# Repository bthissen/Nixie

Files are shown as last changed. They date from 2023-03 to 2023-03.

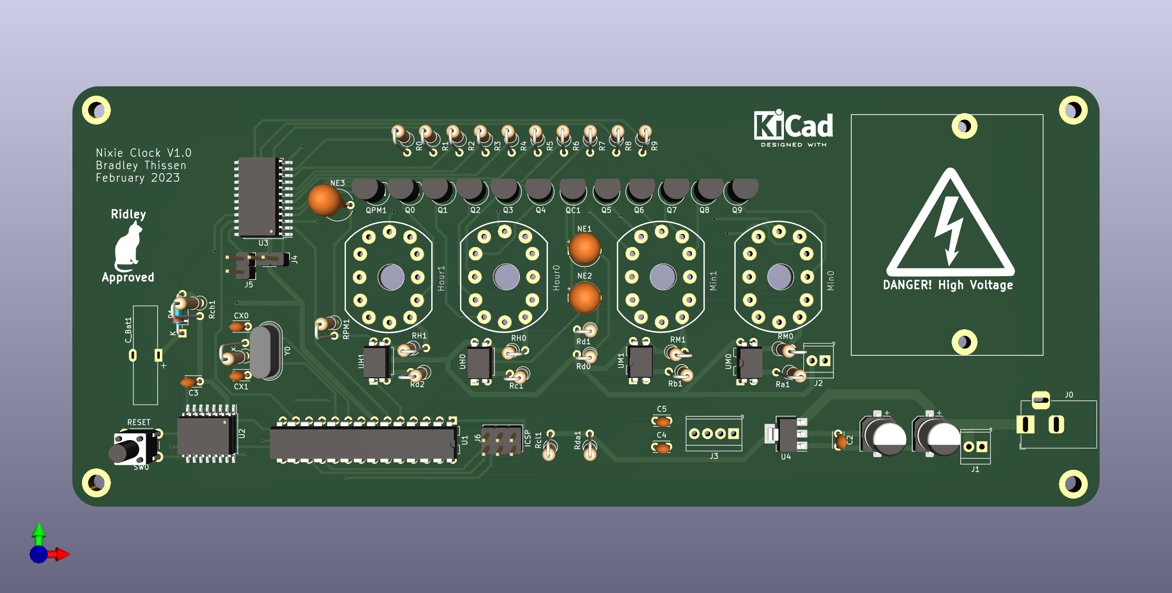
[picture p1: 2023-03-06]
Photos/v1/nixie_clock.png

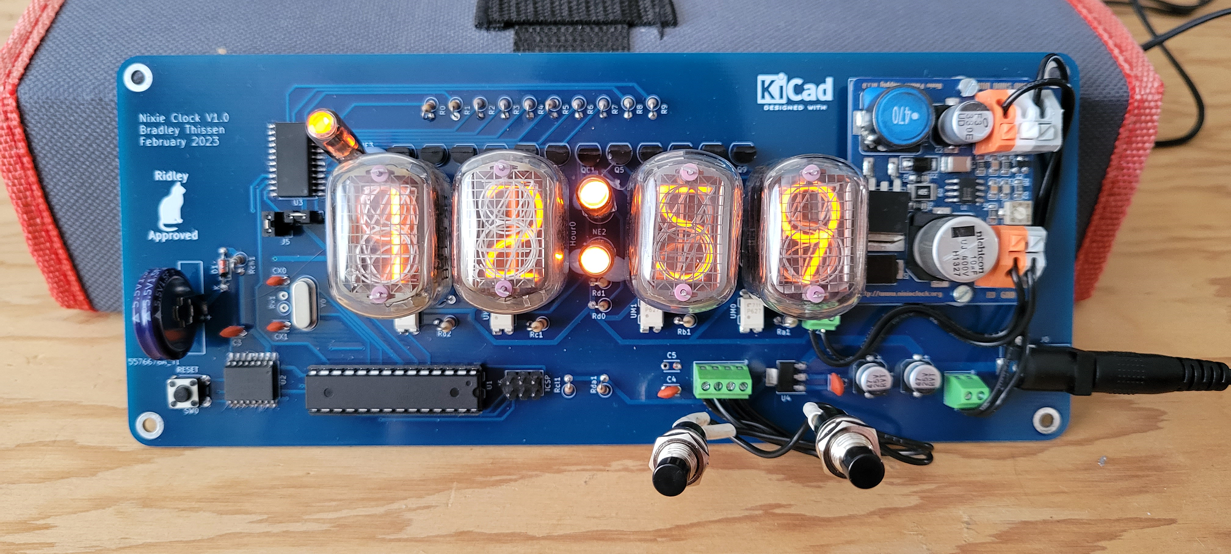
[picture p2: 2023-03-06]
Photos/v1/working_clock.png

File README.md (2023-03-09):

# Nixie

This is the control program for a Nixie Clock using an ATMEGA 328p uC coupled with a DS3231M RTC to maintain and read-back the time
to IN-12B Nixie Tubes and signal with INS-1 Neon indicators (for AM/PM and colon blink). Code is in C and pre-compiled with necessary
.hex to flash directly if needed (need USBASP programmer with ICSP protocol).

Also incluced are KiCAD schematic and PCB files for editing if desired and compiled gerber files for PCB manufacured if wanted. (note: circuit
uses a CD74HC4514 4-to-16 mux to drive the nixie tubes.

#v1.0 initial publish of working model and PCB (currently not using twi.c or twi.h; plan to incorporate for ease of use for TWI protocol
#v1.5 incorporated twi.c and twi.h files for (I2C) implementation (and future modularity); also added 12hr/24hr toggle mode for UI

USAGE:
clock display using 4 nixie tubes arranged as hour(10's) | hour(1's) | minute(10's) | minute(1's) with blinking ':' indicator and 'PM' neon light represent
time over 12 hours (12hr mode only).

Time Setting:
two buttons (set and increment) are used to allow for user program of time and mode. If set button not pressed, increment button acts as toggle mode 
which will switch display from 12 hour to 24 hour and vice-versa.

to set time, press set button once (colon indicator will freeze) and select minutes with increment button to cycle minutes from 0 to 59. Once minutes is decided 
press set button again to increment hours using same increment button (1 to 12 in 12 hr mode; 0 to 24 in 24hr mode). Once hours is selected press set button for 
final time to program time. If done correctly displayed time will be written to DS3231 RTC and colon indicator will begin to blink again.

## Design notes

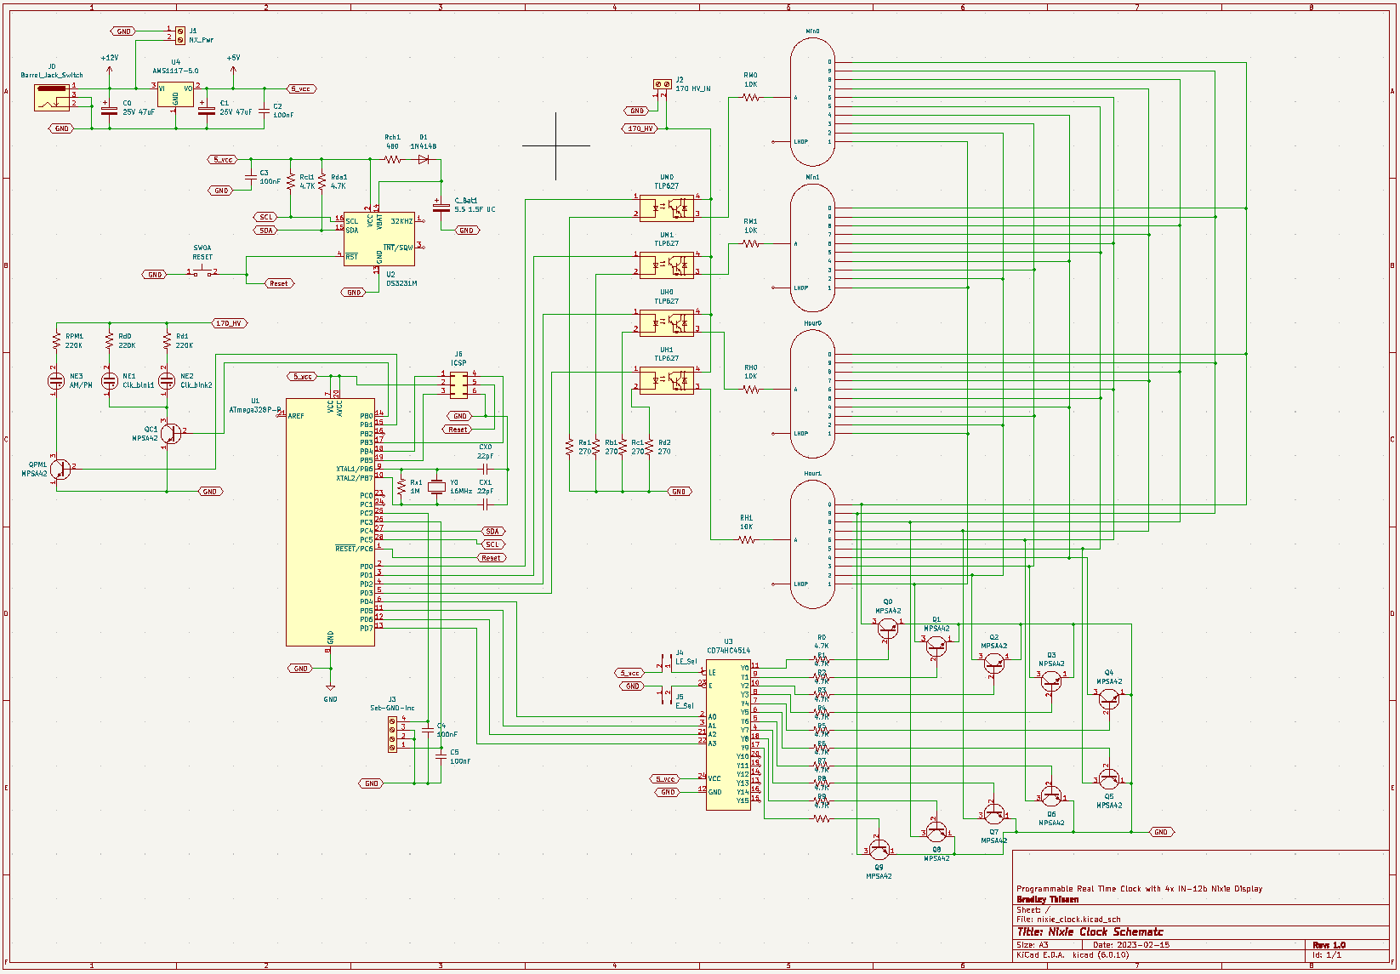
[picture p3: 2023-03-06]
Photos/v1/schematic.PNG

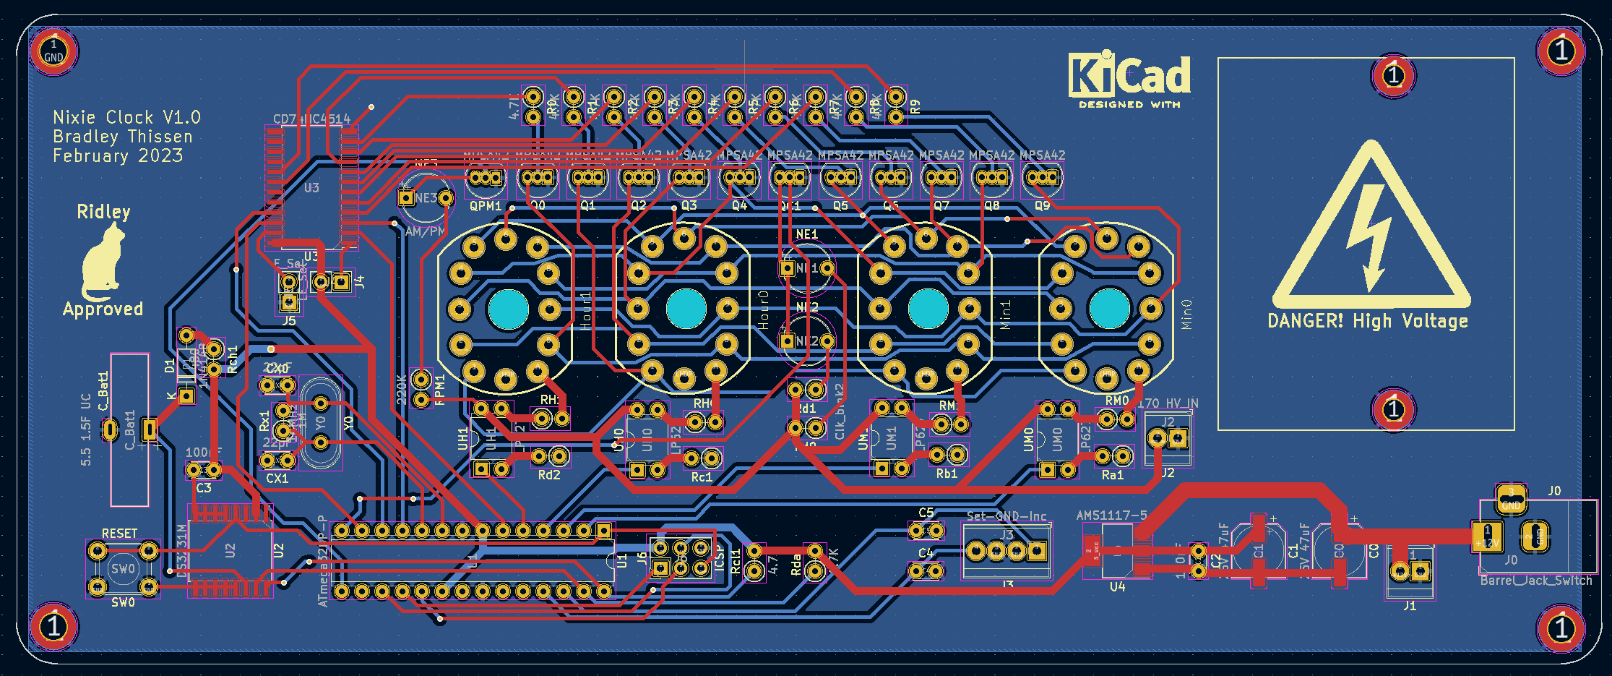
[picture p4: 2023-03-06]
Photos/v1/pcb.PNG

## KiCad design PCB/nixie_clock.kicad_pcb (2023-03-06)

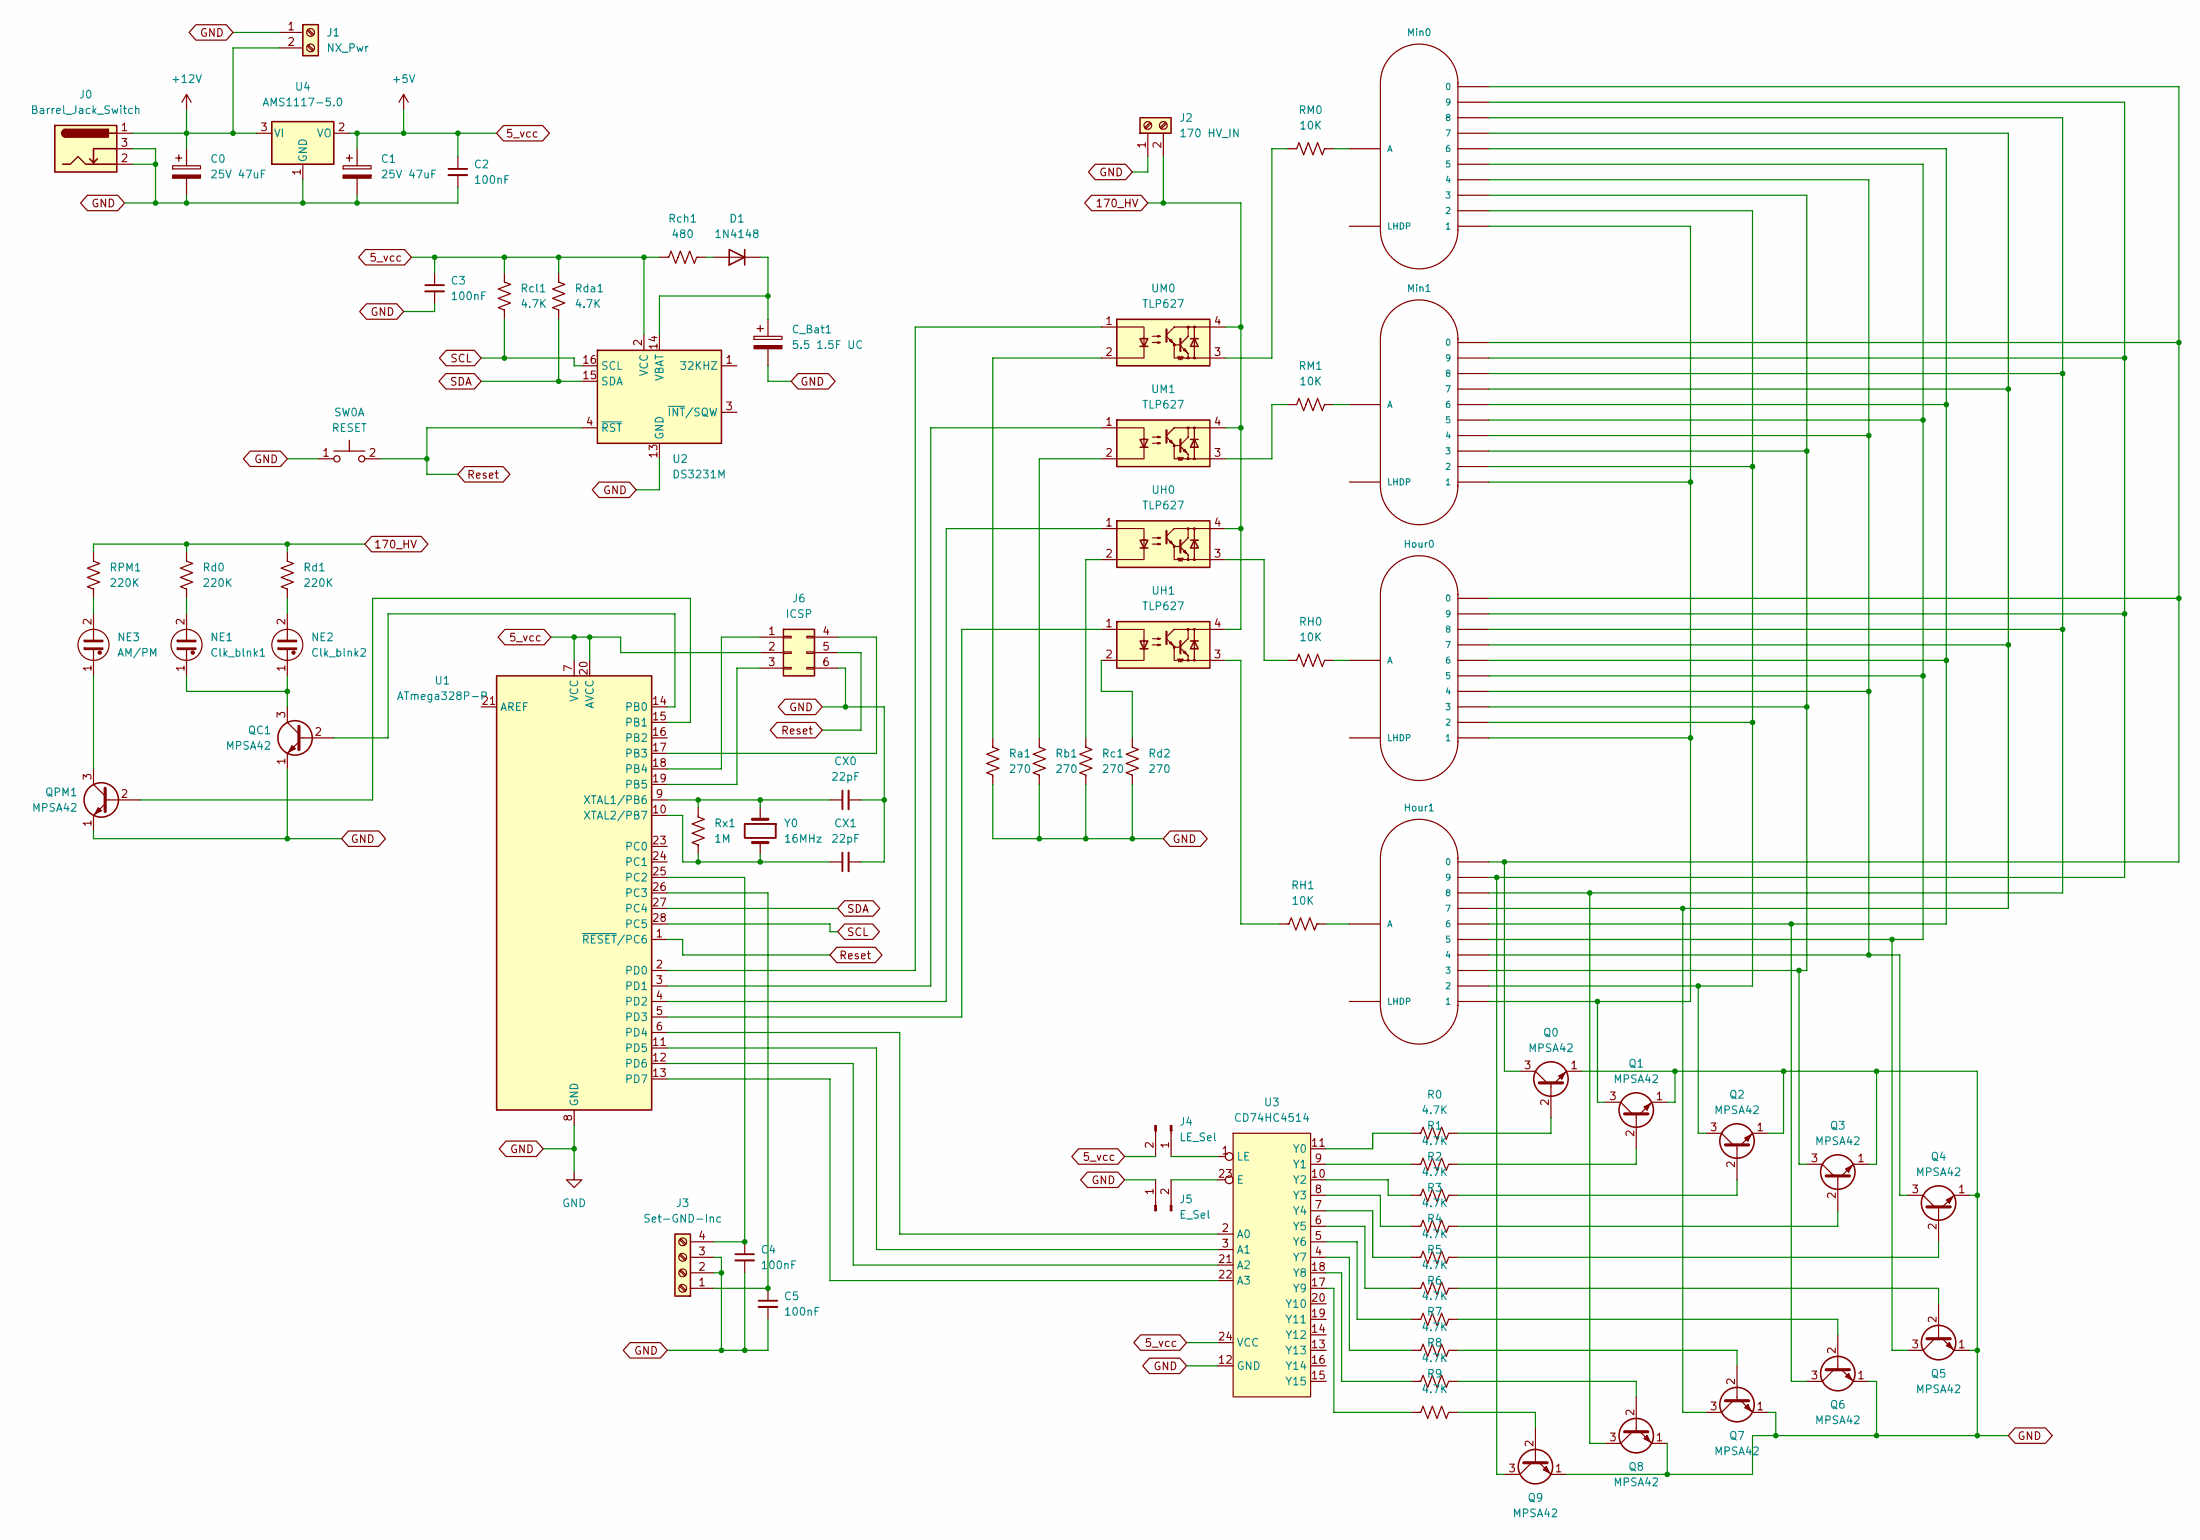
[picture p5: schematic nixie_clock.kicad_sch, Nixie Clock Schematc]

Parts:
C0, C1: 25V 47uF; CP_Elec_6.3x5.9
C2, C3, C4, C5: 100nF; C_Disc_D3.0mm_W2.0mm_P2.50mm
CX0, CX1: 22pF; C_Disc_D3.0mm_W2.0mm_P2.50mm
C_Bat1: 5.5 1.5F UC; DX_5R5VxxxxU_D19.0mm_P5.00mm
D1: 1N4148; D_DO-35_SOD27_P7.62mm_Horizontal
Hour0, Hour1: IN-12BORIGINAL; IN-12
J0: Barrel_Jack_Switch; BarrelJack_Horizontal
J1: NX_Pwr; TerminalBlock_TE_282834-2_1x02_P2.54mm_Horizontal
J2: 170 HV_IN; TerminalBlock_TE_282834-2_1x02_P2.54mm_Horizontal
J3: Set-GND-Inc; TerminalBlock_TE_282834-4_1x04_P2.54mm_Horizontal
J4: LE_Sel; PinHeader_1x02_P2.54mm_Vertical
J5: E_Sel; PinHeader_1x02_P2.54mm_Vertical
J6: ICSP; PinHeader_2x03_P2.54mm_Vertical
Min0, Min1: IN-12BORIGINAL; IN-12
NE1: Clk_blnk1; CP_Radial_Tantal_D6.0mm_P5.00mm
NE2: Clk_blnk2; CP_Radial_Tantal_D6.0mm_P5.00mm
NE3: AM/PM; CP_Radial_Tantal_D6.0mm_P5.00mm
Q0, Q1, Q2, Q3, Q4, Q5, Q6, Q7, Q8, Q9: MPSA42; TO-92_Inline
QC1: MPSA42; TO-92_Inline
QPM1: MPSA42; TO-92_Inline
R0, R1, R2, R3, R4, R5, R6, R7, R8, R9: 4.7K; R_Axial_DIN0207_L6.3mm_D2.5mm_P2.54mm_Vertical
RH0, RH1: 10K; R_Axial_DIN0207_L6.3mm_D2.5mm_P2.54mm_Vertical
RM0, RM1: 10K; R_Axial_DIN0207_L6.3mm_D2.5mm_P2.54mm_Vertical
RPM1: 220K; R_Axial_DIN0207_L6.3mm_D2.5mm_P2.54mm_Vertical
Ra1: 270; R_Axial_DIN0207_L6.3mm_D2.5mm_P2.54mm_Vertical
Rb1: 270; R_Axial_DIN0207_L6.3mm_D2.5mm_P2.54mm_Vertical
Rc1: 270; R_Axial_DIN0207_L6.3mm_D2.5mm_P2.54mm_Vertical
Rch1: 480; R_Axial_DIN0207_L6.3mm_D2.5mm_P2.54mm_Vertical
Rcl1: 4.7K; R_Axial_DIN0207_L6.3mm_D2.5mm_P2.54mm_Vertical
Rd0, Rd1: 220K; R_Axial_DIN0207_L6.3mm_D2.5mm_P2.54mm_Vertical
Rd2: 270; R_Axial_DIN0207_L6.3mm_D2.5mm_P2.54mm_Vertical
Rda1: 4.7K; R_Axial_DIN0207_L6.3mm_D2.5mm_P2.54mm_Vertical
Rx1: 1M; R_Axial_DIN0207_L6.3mm_D2.5mm_P2.54mm_Vertical
SW0: RESET; SW_PUSH_6mm_H7.3mm
U1: ATmega328P-P; DIP-28_W7.62mm
U2: DS3231M; SOIC-16W_7.5x10.3mm_P1.27mm
U3: CD74HC4514; SOIC-24
U4: AMS1117-5.0; SOT-223-3_TabPin2
UH0, UH1: TLP627; DIP-4_W7.62mm
UM0, UM1: TLP627; DIP-4_W7.62mm
Y0: 16MHz; Crystal_HC49-4H_Vertical

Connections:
5_vcc: C1.1, C2.1, C3.1, J4.2, J6.2, Rch1.2, Rcl1.2, Rda1.2, U1.7 (VCC), U1.20 (AVCC), U2.2 (VCC), U3.24 (VCC), U4.2 (VO)
170_HV: J2.2, RPM1.2, Rd0.2, Rd1.2, UH0.4, UH1.4, UM0.4, UM1.4
+12V: C0.1, J0.1, J1.2, U4.3 (VI)
GND: C0.2, C1.2, C2.2, C3.2, C4.2, C5.2, CX0.2, CX1.2, C_Bat1.2, J0.2, J0.3, J1.1, J2.1, J3.2, J3.3, J5.1, J6.6, Q0.1 (E), Q1.1 (E), Q2.1 (E), Q3.1 (E), Q4.1 (E), Q5.1 (E), Q6.1 (E), Q7.1 (E), Q8.1 (E), Q9.1 (E), QC1.1 (E), QPM1.1 (E), Ra1.1, Rb1.1, Rc1.1, Rd2.1, SW0.1 (C), U1.8 (GND), U1.22 (GND), U2.5 (GND), U2.6 (GND), U2.7 (GND), U2.8 (GND), U2.9 (GND), U2.10 (GND), U2.11 (GND), U2.12 (GND), U2.13 (GND), U3.12 (GND), U4.1 (GND)
unnamed: C_Bat1.1, D1.1 (K), U2.14 (VBAT)
unnamed: D1.2 (A), Rch1.1
unnamed: Hour0.A, RH0.2
unnamed: Hour0.0, Hour1.0, Min0.0, Min1.0, Q0.3 (C)
unnamed: Hour0.1, Hour1.1, Min0.1, Min1.1, Q1.3 (C)
unnamed: Hour0.2, Hour1.2, Min0.2, Min1.2, Q2.3 (C)
unnamed: Hour0.3, Hour1.3, Min0.3, Min1.3, Q3.3 (C)
unnamed: Hour0.4, Hour1.4, Min0.4, Min1.4, Q4.3 (C)
unnamed: Hour0.5, Hour1.5, Min0.5, Min1.5, Q5.3 (C)
unnamed: Hour0.6, Hour1.6, Min0.6, Min1.6, Q6.3 (C)
unnamed: Hour0.7, Hour1.7, Min0.7, Min1.7, Q7.3 (C)
unnamed: Hour0.8, Hour1.8, Min0.8, Min1.8, Q8.3 (C)
unnamed: Hour0.9, Hour1.9, Min0.9, Min1.9, Q9.3 (C)
unnamed: Hour1.A, RH1.2
unnamed: C5.1, J3.1, U1.26 (PC3)
unnamed: J4.1, U3.1 (LE)
unnamed: J5.2, U3.23 (E)
unnamed: J6.1, U1.18 (PB4)
unnamed: J6.3, U1.19 (PB5)
unnamed: J6.4, U1.17 (PB3)
unnamed: Min0.A, RM0.2
unnamed: Min1.A, RM1.2
unnamed: NE1.1, NE2.1, QC1.3 (C)
unnamed: NE1.2, Rd0.1
unnamed: NE2.2, Rd1.1
unnamed: NE3.1, QPM1.3 (C)
unnamed: NE3.2, RPM1.1
unnamed: Q0.2 (B), R0.2
unnamed: Q1.2 (B), R1.2
unnamed: Q2.2 (B), R2.2
unnamed: Q3.2 (B), R3.2
unnamed: Q4.2 (B), R4.2
unnamed: Q5.2 (B), R5.2
unnamed: Q6.2 (B), R6.2
unnamed: Q7.2 (B), R7.2
unnamed: Q8.2 (B), R8.2
unnamed: Q9.2 (B), R9.2
unnamed: QC1.2 (B), U1.14 (PB0)
unnamed: QPM1.2 (B), U1.15 (PB1)
unnamed: RH0.1, UH0.3
unnamed: RH1.1, UH1.3
unnamed: RM0.1, UM0.3
unnamed: RM1.1, UM1.3
unnamed: Ra1.2, UM0.2
unnamed: Rb1.2, UM1.2
unnamed: Rc1.2, UH0.2
unnamed: Rd2.2, UH1.2
unnamed: U1.2 (PD0), UM0.1
unnamed: U1.3 (PD1), UM1.1
unnamed: U1.4 (PD2), UH0.1
unnamed: U1.5 (PD3), UH1.1
unnamed: U1.6 (PD4), U3.2 (A0)
unnamed: CX0.1, Rx1.2, U1.9 (XTAL1/PB6), Y0.1
unnamed: CX1.1, Rx1.1, U1.10 (XTAL2/PB7), Y0.2
unnamed: U1.11 (PD5), U3.3 (A1)
unnamed: U1.12 (PD6), U3.21 (A2)
unnamed: U1.13 (PD7), U3.22 (A3)
unnamed: C4.1, J3.4, U1.25 (PC2)
unnamed: R7.1, U3.4 (Y7)
unnamed: R6.1, U3.5 (Y6)
unnamed: R5.1, U3.6 (Y5)
unnamed: R4.1, U3.7 (Y4)
unnamed: R3.1, U3.8 (Y3)
unnamed: R1.1, U3.9 (Y1)
unnamed: R2.1, U3.10 (Y2)
unnamed: R0.1, U3.11 (Y0)
unnamed: R9.1, U3.17 (Y9)
unnamed: R8.1, U3.18 (Y8)
Reset: J6.5, SW0.2 (D), U1.1 (~RESET/PC6), U2.4 (~RST)
SCL: Rcl1.1, U1.28 (PC5), U2.16 (SCL)
SDA: Rda1.1, U1.27 (PC4), U2.15 (SDA)

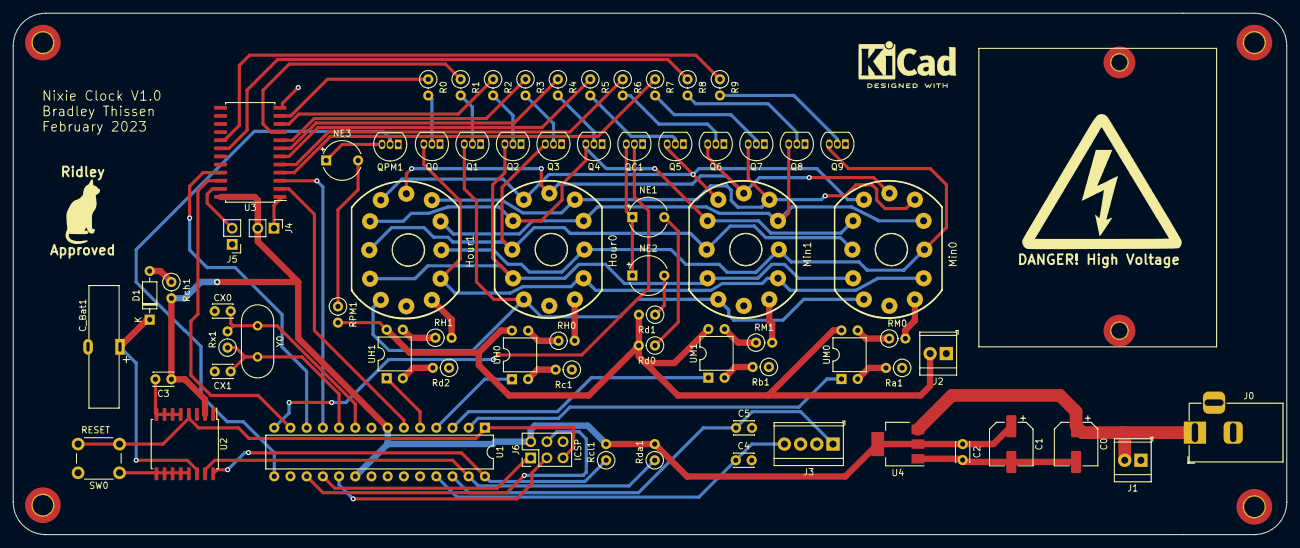
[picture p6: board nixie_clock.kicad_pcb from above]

Board: 2 copper layers, 199.6 x 81.7 mm, 73 parts (0 on the bottom side), 75 nets.

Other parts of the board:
DANGER! High Voltage: LOGO; HVbmp25
Ridley: LOGO; cat10

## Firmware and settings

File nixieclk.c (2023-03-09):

/**************************************************************************
 * Bradley Thissen
 * 
 * Nixie Clock Control Software (v1.5)
 * 
 * writes/reads clock info from RTC (DS3231M)
 * drives IN-12B (x4) Nixie Tubes with neon indicators for display
 * includes every hour tube cycle for cathode poisoning mitigation
 * 
 * Latest version adds twi.h for I2C implementation and toggle 24hr mode
 * 
 * 3/08/2023
***************************************************************************/
#define F_CPU 16000000UL		//set uC clk to 16MHz

#include <avr/io.h>				//enable AVR definitions/Macros
#include <stdlib.h>				//C std lib for basic coding functionality
#include <util/delay.h>			//embedded libraries and delay/timings
#include <string.h>				//c String libraries
#include <stdbool.h>            //bool (binary algebra libraries)
#include "twi.h"                //incorporate TWI (I2C) custom file for implementation

#define RTC_read 0b11010001		//TWI DS3231 adress (1101000) W/R set to 1
#define RTC_write 0b11010000	//TWI DS3231 adress (1101000) W/R set to 0

struct rtc_data{

    uint8_t min;        //hold complete min byte from RTC
    uint8_t hour;       //hold complete hour byte from RTC
    
    uint8_t min0;       //hold only lower nibble (0's min)
    uint8_t min1;       //hold only upper nibble (1's min)
    uint8_t hour0;      //hold only lower nibble (0's hour)
    uint8_t hour1;      //hold only upper nibble (1's hour)

    bool PM;            //store AM/PM bit
    bool twelve_hr;     //store 12hr/24hr bit
};

void nix_num(int nix_sel, int number){  //display given number to selected tube

    DDRD = 0xFF;                        //set port D to all outputs
    uint8_t sel;                        //to add to PORTD for correct tube output

    if (nix_sel == 1){sel = 0xF1;}      //select mintues digit '0'
    else if (nix_sel == 2){sel = 0xF2;} //select hours digit '1'
    else if (nix_sel == 3){sel = 0xF4;} //select minutes digit '0'
    else if (nix_sel == 4){sel = 0xF8;} //select hours digit '1'sel = 0xF8;}
    else {sel = 0xFF;}                  //select all digits on

    _delay_us(4800); //decrease for less flicker but more ghosting (increase for brighter digits) <--------
    
    switch(number){
        case 0 :
            PORTD = (0x0F & sel);       
            break;
        case 1 :
            PORTD = (0x1F & sel);      
            break;
        case 2 :
            PORTD = (0x2F & sel);    
            break;
        case 3 :
            PORTD = (0x3F & sel);  
            break;
        case 4 :
            PORTD = (0x4F & sel);   
            break;
        case 5 :
            PORTD = (0x5F & sel);  
            break;
        case 6 :
            PORTD = (0x6F & sel);  
            break;
        case 7 :
            PORTD = (0x7F & sel);    
            break;
        case 8 :
            PORTD = (0x8F & sel);   
            break;
        case 9 :
            PORTD = (0x9F & sel);  
            break;
        default :
            DDRB = 0x03;                //enable outputs for neons
            PORTB = 0x02;               //turn on the PM indicator (error state number)
            break;
    }
}

void cycle_nix(){

    //int digit = 0;        //remove comment and add loop to increment each digit separately
    int val = 0;

    //for(digit = 1; digit < 5; digit++){       //iterate which tube to display
        for (val = 0; val < 10; val++){         //iterate each number
            nix_num(0,val);                     //display to nixie tube
            _delay_ms(250);                     //150ms delay
        }
    //}
    PORTD = 0x00;                               //no digit selected if out of loop (cycle complete)
}

/*************************DS3231 initialization**********************************/
void clk_init(void){

	twi_init();				//setup TWI
	//twi_start();			//start sequence for TWI

	//twi_write(RTC_write);	//send DS3231 address with write enable
	//twi_write(0x0E);		//select DS3231 addr pointer to control register
	//twi_write(0x1C);		//update control reg with default values (of DS3231 datasheet)
	//twi_stop();		    //stop TWI (need to set ACK to 0 for RTC???)
}

void RTC_set(struct rtc_data set){

	twi_start();
	twi_write(RTC_write);	//upload and send RTC TWI bus address
	twi_write(0x01);		//set RTC pointer reg to minutes (0x00) start

	//begin RTC update (only first three for now to check basic functionality)
	twi_write(set.min);
	twi_write(set.hour);

	twi_stop();				//stop TWI (need to set ACK to 0 for RTC???)
}

struct rtc_data RTC_get(struct rtc_data get){

	twi_start();			//need to init first??? <-------------
	twi_write(RTC_write); 	//select write to RTC to adjust reg pointer
	twi_write(0x01);		//set pointer address of RTC back to 1 or minutes register
	twi_stop();				//stop TWI

	twi_start();			//need to init first??? <-------------
	twi_write(RTC_read);	//set back to read mode to grab the data from RTC

	get.min = twi_read(1);	//read minutes, input into get and send ack to continue
	get.hour = twi_read(0);	//read hours, mask all but the BCD value [(0x1F & twi_read(0))]

	twi_stop();				//stop TWI

	return get;
}
/*************************DS3231 initialization**********************************/

int8_t button_set() { //in theory, this should only run if button is pressed
  static uint16_t state = 0; //holds present state
  state = (state << 1) | (! bit_is_clear(PINC, 2)) | 0xE000;
  if (state == 0xF000) return 1;
  return 0;
}//debounce_switch

int8_t button_inc() { //in theory, this should only run if button is pressed
  static uint16_t state = 0; //holds present state
  state = (state << 1) | (! bit_is_clear(PINC, 3)) | 0xE000;
  if (state == 0xF000) return 1;
  return 0;
}//debounce_switch

int main(){

    DDRD = 0xFF;                         //set outputs for the nixie tubes
    DDRB = 0x03;                         //enable output for colon and PM neons

    DDRC = ((0<< PB2) | (0 << PB3));     //set DDRC pins 2 and 3 as inputs (for buttons)
    PORTC = ((1 << PB2) | (1 << PB3));   //set those same pins as pull ups (logic set as low)

    uint8_t timer = 0x00;                //incrementer for delayed I2C data gather
    bool colon = 1;
    int timeset = 0;

    struct rtc_data set;
    //time to load before bootup for testing only
    //set.min = 0x58;                     //load minutes byte (0x58 == 58 minutes)
    //set.hour = 0x71;                    //load hours byte (set to 11 hours || bit 5 PM indicate)

    clk_init();		                    //initialize DS3231 for operation
	//RTC_set(set);                       //update RTC with default time (if needed)

    cycle_nix();                        //cycle Nixie Tubes on startup

    struct rtc_data clock;
    clock.twelve_hr;                    //default to 12 hour timemode on startup (PM indicate enabled)
    clock = RTC_get(clock);             //read the current time

    clock.twelve_hr = ((0x40 & clock.hour) >> 6); //grab current clock mode (12 or 24 from bit 6 hour reg)

    while(1){

        /************************UI Programming**************************************/
        if(button_set() == 1){           //detect button press for set
            timeset++;
            if(timeset == 3){            //if done with setting time reset and program RTC
                timeset = 0;
                set.hour = clock.hour;   //update set struct with current clock input and program
                set.min = clock.min;
                RTC_set(set);
            }
        }

        if(button_inc() == 1){ 
            if(timeset != 0){
                switch(timeset){
                    case 1 :                                    //increment minutes
                        clock.min0++;
                        if (clock.min0 > 9){
                            clock.min0 = 0x00;
                            clock.min1++;
                            if(clock.min1 > 0x05){clock.min1 = 0x00;}
                        }
                        clock.min = ((clock.min1 << 4) | (clock.min0));
                        break;

                    case 2 :                                   //increment hours and return 12hr setting
                        //clock.hour = (0x1F & clock.hour);        
                        clock.hour0++;
                        if (clock.hour0 > 0x09){
                            clock.hour0 = 0x00;
                            clock.hour1++;   // = 0x01;
                        }

                        if(clock.twelve_hr == 1){   //12 hour mode selected
                            if((clock.hour1 == 0x01) && (clock.hour0 > 0x02)){
                                clock.hour1 = 0;
                                clock.hour0 = 1;
                            }
                            
                            //separate timesetting for 12/24 hour mode
                            if((clock.hour1 == 1) && (clock.hour0 == 2)){
                                clock.PM = !clock.PM;              //toggle AM or PM
                            }
                            clock.hour = ((clock.hour1 << 4) | (clock.hour0));           //upload new time to register
                            clock.hour = ((0x01 << 6) | (clock.PM << 5) | (clock.hour)); //for 12hr (PM mode)
                        }

                        else{   //24 hour mode selected
                            if((clock.hour1 == 0x02) && (clock.hour0 > 0x03)){
                                clock.PM = 0;
                                clock.hour1 = 0;
                                clock.hour0 = 0;
                            }
                            clock.hour = ((clock.hour1 << 4) | (clock.hour0));           //upload new time to register
                            clock.hour = ((0x3F) & (clock.hour));                        //for 24hr mode
                        }
                        break;

                    default :
                        //colon = !colon;
                        break;
                }
            }

            else{ //timeset not enabled toggling to 24hr mode
                if (clock.twelve_hr == 1 && clock.PM == 1){
                
                    clock.hour1 = (clock.hour1 & 0x01); //mask out the PM bit 
                    set.hour0 = (clock.hour0 + 0x02);

                    if(clock.hour0 > 0x09){
                        clock.hour1++;
                        set.hour0 = (clock.hour0 - 0x0A);
                    }

                    set.hour1 = (clock.hour1 + 0x01);
                    set.hour = (0x3F & ((set.hour1 << 4) | (set.hour0)));
                    clock.twelve_hr = 0;
                    clock.PM = 0;           //clear the PM bool

                    //update time to RTC
                    set.min = clock.min; //update minutes reg to current time for upload 
                    RTC_set(set);
                }

                else if (clock.twelve_hr == 1 && clock.PM == 0){ 
                    //if zero hour need adjust 12:xx to 00:xx
                    if(clock.hour1 == 1 & clock.hour0 == 2){
                        set.hour = 0x00; //set hour to zero with PM off and 24 mode
                    }

                    //set 24hr mode and feed current time
                    else{set.hour = (0x3F & ((clock.hour1 << 4) | clock.hour0));}
                    clock.twelve_hr = 0;
                    set.min = clock.min;
                    RTC_set(set);
                }

                //convert 24hr to 12hr time
                else if (clock.twelve_hr == 0) {

                    set.hour1 = clock.hour1;
                    set.hour0 = clock.hour0;
                    
                    //set to PM state
                    if(clock.hour > 0x12){
                        set.hour1 = (clock.hour1 - 0x01);
                        set.hour0 = (clock.hour0 - 0x02);

                        clock.PM = 1;
                    }

                    //0 hour (between 2400 and 100 hours)
                    if((clock.hour1 == 0x00) && (clock.hour0 == 0x00)){
                        set.hour1 = 0x01;
                        set.hour0 = 0x02;  //set hour to 12:xx (AM)

                        clock.PM = 0;
                    }

                    set.hour = ((0x01 << 6) | (clock.PM << 5) | (set.hour1 << 4) | (set.hour0));
                    clock.twelve_hr = 1;
                    
                    //update time to RTC
                    set.min = clock.min; //update minutes reg to current time for upload 
                    RTC_set(set);
                }
            }
        }  
        /************************UI Programming**************************************/

        if ((timer == 0x38) && (timeset == 0)){
            clock = RTC_get(clock); //read the current time
            colon = !colon;         //toggle colon
            timer = 0x00;

            if (clock.min == 0){    //start of the hour
            cycle_nix();            //cycle Nixie Tubes prevent cathode poisoning
            }
        }

        //feed time into set values for nixie diplay
        clock.min0 = (0x0F & clock.min);
        clock.min1 = ((0xF0 & clock.min) >> 4);

        clock.hour0 = (0x0F & clock.hour);
        clock.hour1 = ((0xF0 & clock.hour) >> 4);
        clock.hour1 = (clock.hour1 & 0x03);

        if((clock.hour1 == 0x02) && (clock.twelve_hr == 1)){
            clock.PM = 1;
            clock.hour1 = 0x00;
        }
        else if(clock.hour1 == 0x03){
            clock.PM = 1;
            clock.hour1 = 0x01;
        }

        else if((clock.hour1 == 0x00) || (clock.hour1 == 0x01)){
            clock.PM = 0;
        }

        else if(clock.twelve_hr == 0){clock.PM = 0;}

        PORTB = ((colon << PB0) | (clock.PM << PB1));

        //display values to nixie tube
        nix_num(1, clock.min0);
        nix_num(2, clock.min1);
        nix_num(3, clock.hour0);
        if(clock.hour1 != 0){
            nix_num(4, clock.hour1);
        }
        timer++;
    }
    return 0;
}

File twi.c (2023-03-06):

/********************************************
*	Bradley Thissen
*	07/25/2018
*	
*	main file for implementing TWI (I2C)
*	for AVR architecture (mainly atmega328p)
*********************************************/
#define F_CPU 16000000UL
#include <avr/io.h>
#include <util/delay.h>
#include "twi.h"


//initialize TWI (I2C)
void twi_init() {
	TWSR=0x00;	//set prescale bits to zero (1)
	TWBR=0x48;	//[Fclk / (2*TWBR*prescale + 16) ] = SCL	(16MHz, TWBR=72) SCL ~ 100kHz
	TWCR=0x04;	//enable TWU register	(1<<TWEN)
}

//Start TWI Communication
void twi_start() {
	TWCR = ((1<<TWINT) | (1<<TWSTA) | (1<<TWEN));
	while (!(TWCR & (1<<TWINT)));		//loop until complete
}

//End TWI communication
void twi_stop(void) {
	TWCR = ((1<<TWINT) | (1<<TWEN) | (1<<TWSTO));
	_delay_us(100);	//delay a short time for cleanup
}

//Output data over TWI (I2C)
void twi_write(uint8_t v_twidata){
	TWDR = v_twidata;					//set data into buffer register
	TWCR = ((1<<TWINT) | (1<<TWEN));	//reset interrupt flag and  enable
	while (!(TWCR & (1<<TWINT)));		//loop until complete
}

//Read data from TWI (I2C)
uint8_t twi_read(uint8_t v_ackoption) {
	TWCR = ((1<<TWINT) | (1<<TWEN) | (v_ackoption<<TWEA));	//reset flag, enable, set acknowledge bit
	while ( !(TWCR & (1 <<TWINT)));							//loop until complete
    return TWDR;
}

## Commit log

2023-03-06 Initial commit of Nixie Clock Files to Github with working basic functionality (added compiled files for direct programming of ATMEGA 328p if desired)
    Also added PCB with gerber files and raw KiCAD files for editing or
    re-production if desired
2023-03-09 final revision to retain time on reset
    [nixieclk.c]
